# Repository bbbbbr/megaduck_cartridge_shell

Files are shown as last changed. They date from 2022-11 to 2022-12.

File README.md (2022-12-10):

## 3D Printable Cartidge Shell for the Mega Duck Console

The [Mega Duck](https://en.wikipedia.org/wiki/Mega_Duck) / Cougar Boy is a (1993) hardware clone of the Game Boy with some register changes and a different cartridge format.

Until now there have been no aftermarket Cartridge Shells available for the Mega Duck. This 3D printable design can be used to avoid harvesting OEM shells for use with Flash Cartridge PCBs.

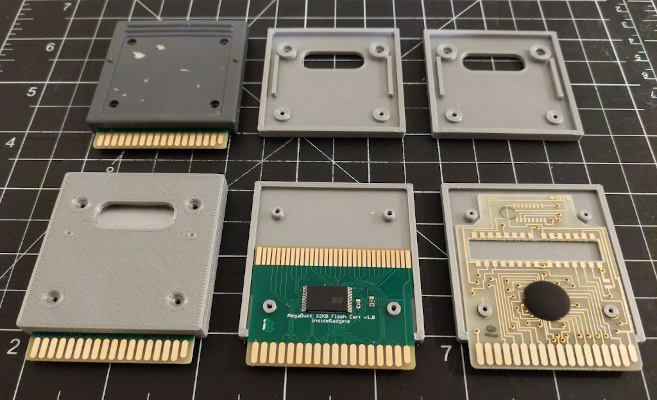
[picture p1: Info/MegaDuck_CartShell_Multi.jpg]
Picture of Several 3D Printed Mega Duck Cart Shells with OEM and Inside Gadgets Circuit Boards installed


## Features:
- Compatible with OEM and Inside Gadgets Mega Duck cartidge PCBs
- Opens easily and parts remain aligned without screws for easier programming access during development
- Screws can be used to lock the top and bottom parts together

## 3D Printing and Design
The design has been printed with success in PLA.

- Use the `.stl` files for printing (See [Releases](https://github.com/bbbbbr/megaduck_cartridge_shell/releases) or [Thingiverse](https://www.thingiverse.com/bbbbbr/designs))
- Use the `.FCStd` files for modifying the design (FreeCAD 20.1)

This was my first design using FreeCAD so there are things which should be done differently, but which I'm not going to go back and fix for now (such as fillets mixed in, instead of all last).

## GBXCart Programming Jig
An improved adapter jig for programming the Inside Gadgets cartridge with a gbxcart is also included in this repo.

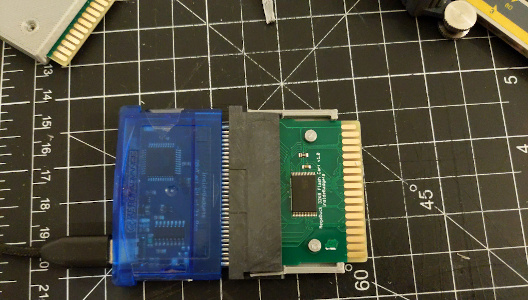
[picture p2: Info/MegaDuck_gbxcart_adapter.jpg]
Picture of Inside Gadgets Mega Duck cartridge PCB plugged into a gbxcart using the 3D printed adapter jig


## Screws
To avoid scratching the inside of the cartridge slot use screws with a pan head of ~1.2mm or less (so they fit completely within the screw hole recesses). 
Depending on the fidelity of the 3D print it may be necessary to slightly ream out the screw holes.

Compatible screws:
- [#21534 at MetricScrews.us](https://www.metricscrews.us/index.php?main_page=product_info&cPath=98_298_300&products_id=1248)
  - M1.7x3 Steel / Nickel Pan Head Phillips Machine Screw, Pan Head Height & Diameter: 1.1mm, 3.2mm
- [#20612 at MetricScrews.us](https://www.metricscrews.us/index.php?main_page=product_info&cPath=98_298_300&products_id=506)
  - M1.7-0.35 x 3.5mm C1018 / Steel / Nickel Pan Head Phillips Machine Screw, Pan Head Height & Diameter: 1.1mm, 3.2mm

## Available Flash Carts

### Inside Gadgets
Inside Gadgets sells a 32K Mega Duck flash cart with RAM and no MBC (~$9). It can be used with this cartridge shell design.
- Has a Game Boy cartridge connector on the other end so that it can be programmed with the a gbxcart.
- Cartridge: https://shop.insidegadgets.com/product/megaduck-32kb-flash-cart/
- GBXCart programmer: https://www.gbxcart.com/

### a2heaven
a2heaven.com sells a Multi-Cart (~$66) which comes in ready made shell, so no 3D Printed shell is required.
http://www.a2heaven.com/webshop/index.php?rt=product/product&product_id=172

## Development Tools
As of [GBDK-2020](https://github.com/gbdk-2020/gbdk-2020) 4.0.6 it is now possible to write software for the Mega Duck in C.

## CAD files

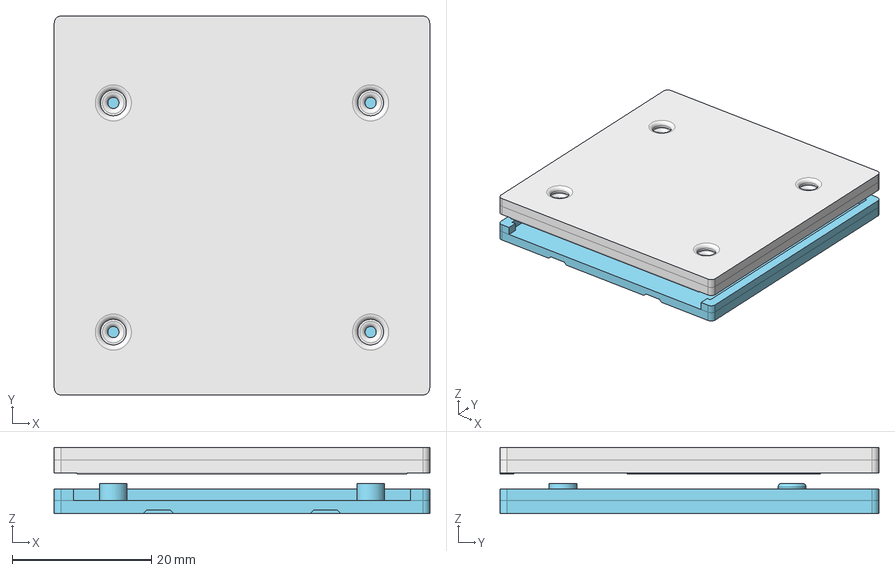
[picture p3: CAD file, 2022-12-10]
Source Files/MegaDuck_Cartridge_Shell_No_Grip.FCStd
54.0 x 54.5 x 9.50 mm
Cart Shell Bottom
Cart Shell Top

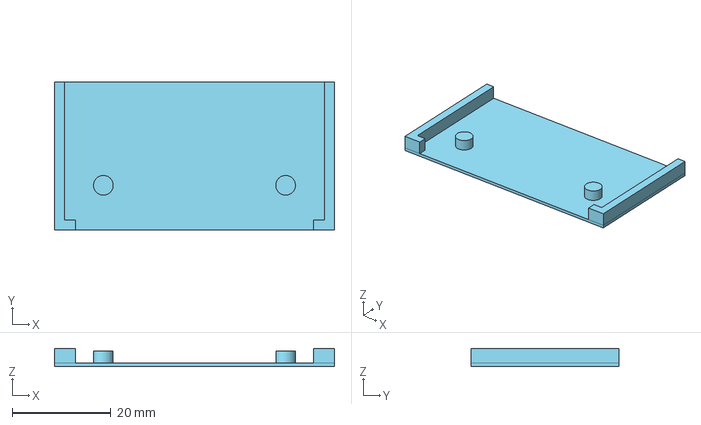
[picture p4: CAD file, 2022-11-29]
Source Files/MegaDuck_Programming_Jig.FCStd
56.9 x 30.0 x 3.70 mm

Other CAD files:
Source Files/MegaDuck_Cartridge_Shell.FCStd

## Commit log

2022-11-28 v0.9 Initial check in of FreeCad source and stl files
    [MegaDuck_Cartridge_Shell.FCStd, MegaDuck_Programming_Jig.FCStd]
2022-11-29 GBXCart Adapter: Fix GB width (+2.1mm), add more tolerance to Duck side. v1.0
    [MegaDuck_Programming_Jig.FCStd]
2022-11-29 gitignore: ignore non-zipped STL files
2022-11-29 Cart Shell: v1.0: - 0.1mm more tolerance for front Duck connector guides - Cart total thickness 7.30mm printed to ~7.50-7.60mm, so adding 0.15mm more tolerance by thinning cart top base - Screw holes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
    [MegaDuck_Cartridge_Shell.FCStd]
2022-12-10 Cart Shell: v1.0: Version with no Grip cutout and stopper holes on top of shell
    [MegaDuck_Cartridge_Shell_No_Grip.FCStd]
